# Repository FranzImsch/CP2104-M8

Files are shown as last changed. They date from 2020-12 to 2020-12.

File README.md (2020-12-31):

# CP2104-M8

CP2104 Breakout Board with USB-C and Reset Circuit for ESP-Chips. Features standard FTDI-Header as well as Tag Connect (TC2030) header (Check schematic for pinout). Components were selected so that only Basic Parts from JLCPCB's SMT Assembly Service are used (With the exception of the voltage regulator!).

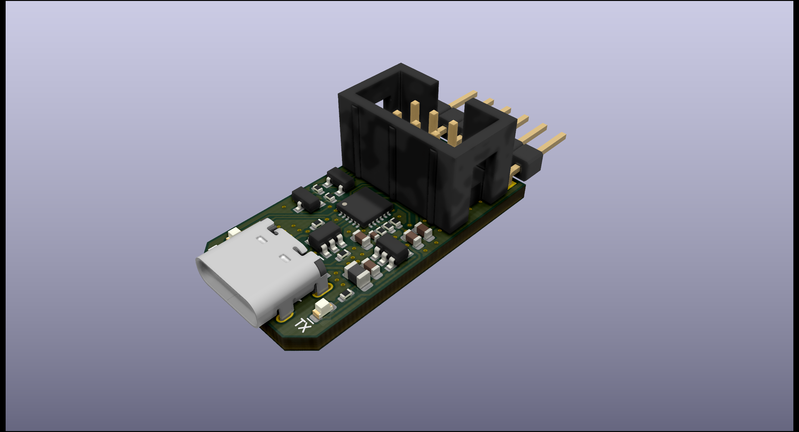
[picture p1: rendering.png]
Rendering


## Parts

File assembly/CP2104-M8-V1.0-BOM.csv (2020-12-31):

Comment | Designator | Footprint | LCSC
100nF | C1 | Capacitor_SMD:C_0402_1005Metric | C1525
4.7µF | C3 | Capacitor_SMD:C_0603_1608Metric | C19666
2.2µF | C2,C4,C5 | Capacitor_SMD:C_0603_1608Metric | C23630
TX-LED | D1 | LED_SMD:LED_0603_1608Metric | C72043
RX-LED | D2 | LED_SMD:LED_0603_1608Metric | C72041
Ferrite_Bead_Small | FB1 | Inductor_SMD:L_0805_2012Metric | C1015
C393939 Conn | J1 | Connector_USB:USB_C_Receptacle_HRO_TYPE-C-31-M-12
Tag-Connect-Out | J2 | Connector_IDC:IDC-Header_2x03_P2.54mm_Vertical
FTDI-EQUIV | J3 | Connector_PinSocket_2.54mm:PinSocket_1x06_P2.54mm_Horizontal
S8050 | Q1,Q2 | Package_TO_SOT_SMD:SOT-23 | C2146
1kΩ | R1,R2 | Resistor_SMD:R_0402_1005Metric | C11702
5.1kΩ | R3,R6 | Resistor_SMD:R_0402_1005Metric | C25905
24kΩ | R4 | Resistor_SMD:R_0402_1005Metric | C25769
47kΩ | R5 | Resistor_SMD:R_0402_1005Metric | C25792
4.7kΩ | R7 | Resistor_SMD:R_0402_1005Metric | C25900
10kΩ | R8,R9 | Resistor_SMD:R_0402_1005Metric | C25744
CP2104 | U1 | Package_DFN_QFN:QFN-24-1EP_4x4mm_P0.5mm_EP2.6x2.6mm | C47742
TLV75533PDBV | U2 | Package_TO_SOT_SMD:SOT-23-5
SRV05-4 | U3 | Package_TO_SOT_SMD:SOT-23-6 | C85364

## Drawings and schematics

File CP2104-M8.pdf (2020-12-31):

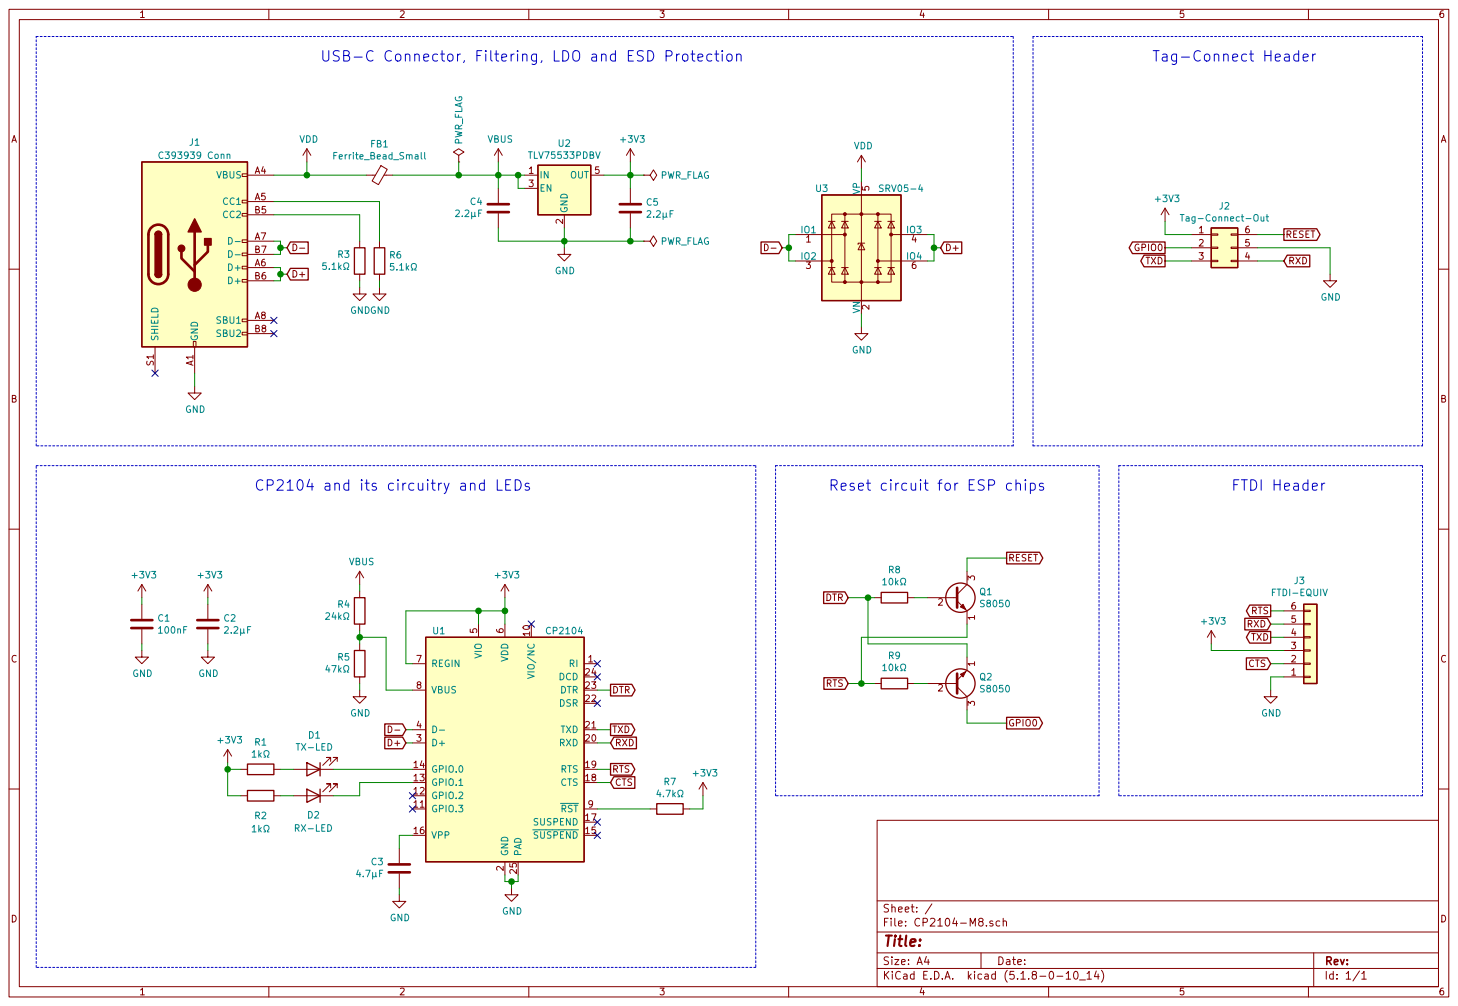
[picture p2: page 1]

2 RXD 20 TXD 21 DSR 22 DTR 23 DCD 24 PAD 25 D+ 3 D- 4 VIO

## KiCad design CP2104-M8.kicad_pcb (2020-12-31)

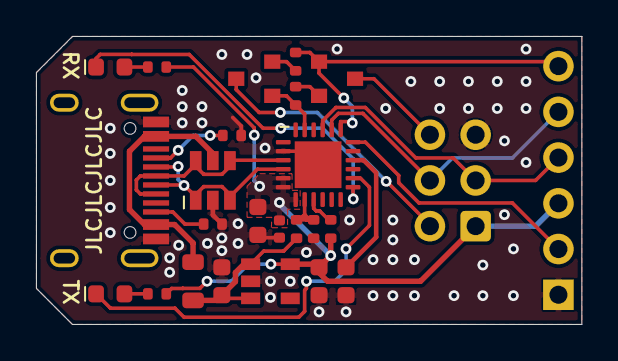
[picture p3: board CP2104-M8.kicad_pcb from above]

Board: 2 copper layers, 30.3 x 16.0 mm, 25 parts (0 on the bottom side), 24 nets.

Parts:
C1: 100nF; C_0402_1005Metric
C2, C4, C5: 2.2µF; C_0603_1608Metric
C3: 4.7µF; C_0603_1608Metric
D1: TX-LED; LED_0603_1608Metric
D2: RX-LED; LED_0603_1608Metric
FB1: Ferrite_Bead_Small; L_0805_2012Metric
J1: C393939 Conn; USB_C_Receptacle_HRO_TYPE-C-31-M-12
J2: Tag-Connect-Out; IDC-Header_2x03_P2.54mm_Vertical
Je: FTDI-EQUIV; PinSocket_1x06_P2.54mm_Horizontal
Q2: S8050; SOT-23
Qe: S8050; SOT-23
R1, R2: 1kΩ; R_0402_1005Metric
R3: 5.1kΩ; R_0402_1005Metric
R4: 24kΩ; R_0402_1005Metric
R5: 47kΩ; R_0402_1005Metric
R6: 5.1Ω; R_0402_1005Metric
R7: 4.7kΩ; R_0402_1005Metric
R8, R9: 10kΩ; R_0402_1005Metric
U1: CP2104; QFN-24-1EP_4x4mm_P0.5mm_EP2.6x2.6mm
U2: TLV75533PDBV; SOT-23-5
U3: SRV05-4; SOT-23-6

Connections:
+3V3: C1.1, C2.1, C5.1, J2.1, Je.3, R1.2, R2.2, R7.1, U1.5, U1.6, U1.7, U2.5
CTS: Je.2, U1.18
D+: J1.A6, J1.B6, U1.3, U3.4, U3.6
D-: J1.A7, J1.B7, U1.4, U3.1, U3.3
DTR: Q2.1, R8.1, U1.23
GND: C1.2, C2.2, C3.1, C4.1, C5.2, J1.A1, J1.A12, J1.B1, J1.B12, J2.5, Je.1, R3.1, R5.1, R6.2, U1.2, U1.25, U2.2, U3.2
GPIO0: J2.2, Q2.3
unnamed: C3.2, U1.16
unnamed: D1.1, U1.14
unnamed: D1.2, R1.1
unnamed: D2.1, U1.13
unnamed: D2.2, R2.1
unnamed: J1.A5, R6.1
unnamed: J1.B5, R3.2
unnamed: Qe.2, R8.2
unnamed: Q2.2, R9.2
unnamed: R4.1, R5.2, U1.8
unnamed: R7.2, U1.9
RESET: J2.6, Qe.3
RTS: Je.6, Qe.1, R9.1, U1.19
RXD: J2.4, Je.5, U1.20
TXD: J2.3, Je.4, U1.21
VBUS: C4.2, FB1.1, R4.2, U2.1, U2.3
VDD: FB1.2, J1.A4, J1.A9, J1.B4, J1.B9, U3.5

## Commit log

2020-12-31 initialise repo
    [CP2104-M8-V1.0-BOM.csv, CP2104-M8-V1.0-PANELISED.kicad_pcb, CP2104-M8.kicad_pcb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]
2020-12-31 added schematic
